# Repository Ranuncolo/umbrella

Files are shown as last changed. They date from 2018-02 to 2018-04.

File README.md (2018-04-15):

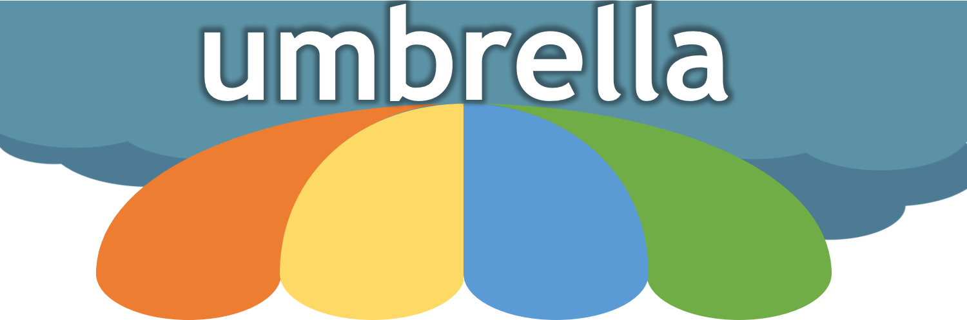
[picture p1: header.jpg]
Umbrella!


# umbrella

Umbrella is a weather station based on Raspberry Pi.

Umbrella!

Video demonstration:

https://www.youtube.com/watch?v=GxtKGGudiI4

## Introduction
Have you ever wondered what the local weather conditions are in your garden? Wouldn't you like a simple way to get all the necessary data for growing the best possible plants in your garden? 

We have created a Raspberry Pi based Weather station that collects and displays all its data in a very easy to understand graphed format. The device contains temperature, humidity, air pressure, ambient light and wind sensors.
It will also provide you weather data with up-to-the-minute precision.

This device will be significantly smaller and cheaper than a conventional weather station :)

## Technical Description

Although the weather can change relatively quickly, you don't need to sample the weather very frequently to plot interesting weather trends.  As this code will sample and record the weather every minute, a latency of a few seconds would be acceptable.  Only a single sample needs to be stored in the memory buffer at any one time as data can be saved to the SD card onboard the Pi.

Code is implemented in userspace.  The reduction in latency gained by running in kernel space is not required.  As the program is paired with a web app it is safer to deny the program access to the kernel, ensuring that the kernel remains protected.  This software required two threads - one for the data processing software and one for the web app.

Communication with the sensors is accomplished using the I<sup>2</sup>C protocol.  While the SPI protocol is much simpler and requires a lower processing overhead, the I<sup>2</sup>C protocol  only requires two lines connected to the Pi allowing for simpler circuitry.  Processing speed was not a priority for these devices.  For the wind speed however, an ADC with SPI was used to allow many samples to be taken across a short period of time.  The sensors contain internal reed switches that are triggered as the device rotates.  Counting rotations over a period of 3s allows a good average wind speed to be detected.

The project is split into roughly three equal parts.  Equal work share was ensured through constant communication with other group members and offering help where possible.   These parts were: 

1. Hardware and electronic circuit design - [Paul Harrison](http://github.com/pbh001)
2. Data processing onboard the Raspberry Pi - [Rene Gaio](http://github.com/Ranuncolo)
3. Data visualisation in a web browser - [Daniel Marwick](http://github.com/danmarwick)

Hardware was therefore allocated approximately one third of the time was spent on hardware and the rest on software.  Debugging of the hardware was done on a bread board as components arrived.  Debugging of software was done as features were coded. The connectivity of these parts of the system can be see in the block diagram below.

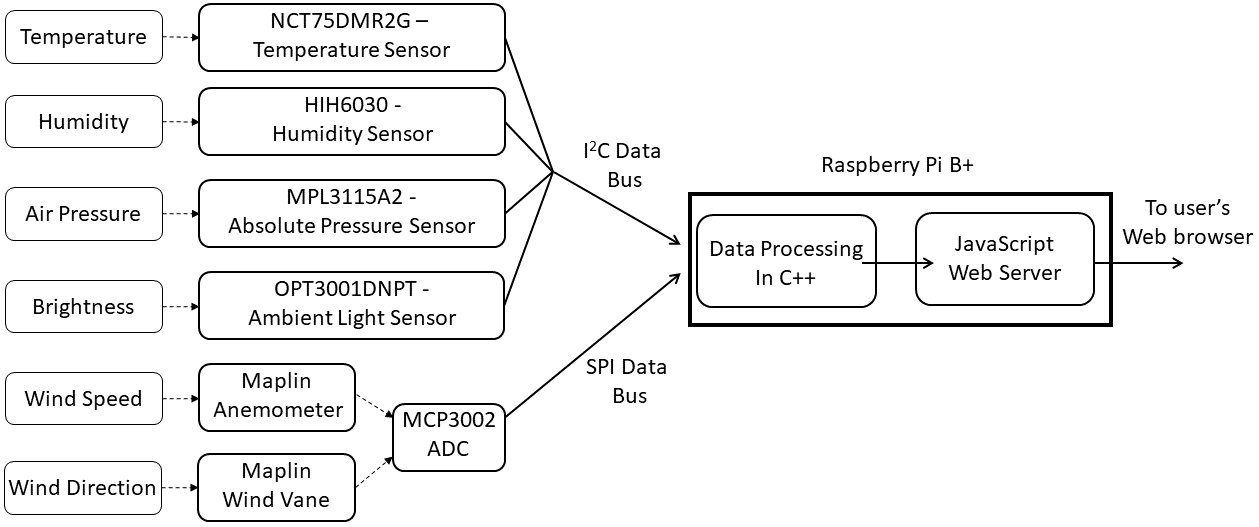
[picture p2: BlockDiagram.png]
Block Diagram


Data is read from the sensors in binary format, converted to numeric values and stored in human readable csv files with conventional SI units.  A web server script is running on the Pi listening for data requests in port 32000.  When a request is made by a web browser on the network, our web app is transmitted to said web browser.  The web app plots the data using the dygraphs package within Javascript.  The benefit of Javascript is the client side execution that allows the data to be plotted on the user's web browser without adding too much load to the processor on the Pi.

The device and software are marketed using Twitter and Facebook, sharing on relevant hashtags to reach our target market.  Version control is handled using git, with version 1.0 being our initial release when we reach a minimum viable product.  Hardware and software has been split between the team members as described above.

This project is deemed succesful when it is able to detect, record and display weather data in both real time and graphed formats.

## Required Components

1. Raspberry Pi Model B+ - (newer models are available and are recommended due to faster processor and onboard WiFi)

2. Sensors

   A. [NCT75DMR2G - I<sup>2</sup>C Digital Temperature sensor](http://uk.farnell.com/on-semiconductor/nct75dmr2g/temperature-sensor-3deg-c-msop/dp/2627996)

   B. [HIH6030 - I<sup>2</sup>C Digital Humidity sensor](http://uk.farnell.com/honeywell/hih6030-021-001/sensor-humidity-no-filter-4-5/dp/2356755?st=hih6030-021-001)

   C. [MPL3115A2 - I<sup>2</sup>C Digital Pressure sensor](http://uk.farnell.com/nxp/mpl3115a2/pressure-sensor-20-110kpa-8lga/dp/2009084)

   D. [OPT3001DNPT - I<sup>2</sup>C Digital Ambient Light Sensor](http://uk.farnell.com/texas-instruments/opt3001dnpt/ambient-light-sensor-uson-6/dp/2504234)
   
   E. [Maplin Anemometer](https://www.ebay.co.uk/p/Maplin-Replacement-Anemometer-for-Use-With-Wireless-Weather-Stations-N96gy/2254341215)
   
   F. [Maplin Wind Vane](https://www.ebay.co.uk/itm/Maplin-Replacement-Wind-Direction-Sensor-For-N96Fy-N96Gy-External-/201278499640)
   
3. [MCP3002 - SPI Analogue to Digital Converter](http://uk.farnell.com/microchip/mcp3002-i-p/ic-adc-10bit-200ksps-pdip-8/dp/1852015)

#### Notes
 - The I<sup>2</sup>C sensors require only four pins for the entire set of sensors.
 
        - Pin 1 - 3.3V
            
        - Pin 3 - Data
            
        - Pin 5 - Clock
           
        - Pin 6 - Ground
           
- Most devices used in this project are surface mount ICs that can be difficult to solder without access to the right equipment.  Hobbyists may wish to look for equivalent through-hole sensors that can be mounted to veroboard more easily for a simpler version that can be easily assembled at home.  

- The pressure sensor has an awkward package with a metal case and pads on the bottom surface. It is especially difficult to solder!

- Our wind sensors are mounted on a 3D printed arm with slightly imprecise measurements that required the wind sensors to be awkwardly bolted on.  When creating 3D printed elements be sure that your component will be compatible with the sensors.

- Due to time constraints we were unable to create a case or an outdoor power supply solution.  These are left as a project for you, dear reader!

## Installation Instructions

### Data Processing Software
When running your Raspberry Pi for the first time run the following in the terminal to locate and install any updates to the default packages.

 > sudo apt-get update
 
 > sudo apt-get upgrade

To enable I<sup>2</sup>C devices on your Raspberry Pi you must install the following package: 

 > sudo apt-get install i2c-tools
 
To enable our devices on your Raspberry Pi you must make the following change to the OS:

 > sudo raspi-config

Then go to Interfacing Options > Advanced > I2C > Enable
Also Interfacing Options > Advanced > SPI > Enable

In the final code it is possible to run all the sensors together compiling:

> g++ umbrella.cpp geti2c.cpp computation.cpp WindSpi.cpp -o weather

> ./weather

#### Notes
- When working with I<sup>2</sup>C sensors you must be careful to only read in the number of bits specified by the datasheet.  While you must read whole bytes from the chip, the relevant data is often comprised of a non-integer number of bytes - such as 12 bits.  Reading in these extra bits into your data can give erroneous readings.
- While all I<sup>2</sup>C sensors transmit data in a similar format, there are minor variations between each sensor and component manufacturers don't always write the clearest instructions.

### Javascript Web App
Adding webserver functionality to your Raspberry Pi is simple!  All you have to do is install Node.Js for Debian.  This can be accomplished using two commands:

> wget http://<i></i>node-arm.herokuapp.com/node_latest_armhf.deb

> sudo dpkg -i node_latest_armhf.deb

The first line should download the latest version of Node.Js for Debian.  The second command should install the package.

At this stage you should be able to run .js scripts from the command line using the command "node filename.js".  You can go one step further to get your web app code to launch when the Raspberry Pi boots up by editing your rc.local file.  As always, care should be taken when editing files that affect how the system boots up.  Small errors can easily prevent the device from starting at all!

First open the file with:

> sudo nano /etc/rc.local

then add the following line of code above the "exit 0" line.  Do not delete the "exit 0" line!

> sudo node ~/final/webserver.js &

If you save your code in a different folder then change the full path of the webserver.js file accordingly.

#### Notes
- The "&" symbol in the rc.local file is crucial for this code. It creates a new branch for the webserver code and allows it to run in the background.  If we were to omit this symbol then the Pi would wait for the script to finish executing before continuing with the boot process.  However, this code runs continuously so the boot process would never finish!
- The webserver code includes the IP address of the Pi and the port over which web app will be transmitted.  The IP address of your Pi on your network can be determined by typing "ifconfig" in the command line.  If you are unsure what ports are available for communication over your local network, then contact your network administrator.
  
### Contact    
    
Email: UmbrellaRPI@gmail.com
    
Twitter: https://twitter.com/UmbrellaRPI
    
Facebook: https://www.facebook.com/UmbrellaRPI

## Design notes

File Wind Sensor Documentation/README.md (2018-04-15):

# Wind Sensor Documentation

## Electronics and magnet of the Anemometer.
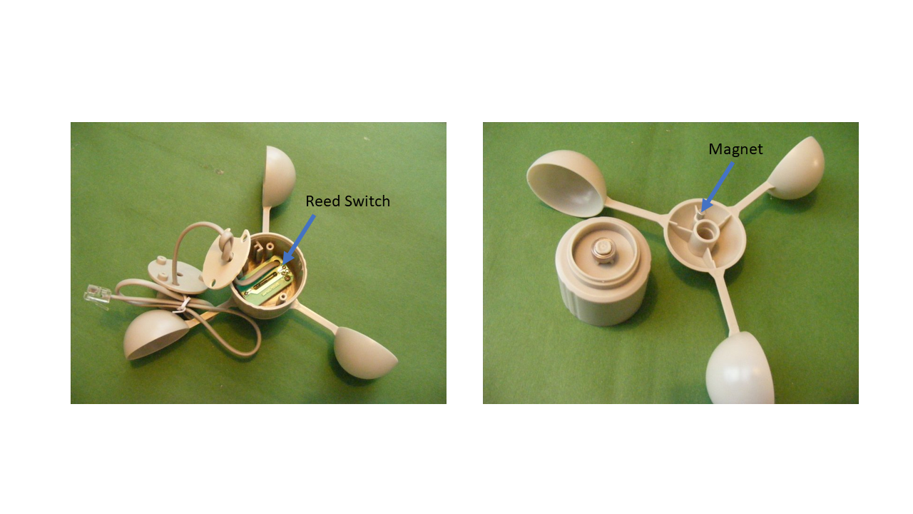
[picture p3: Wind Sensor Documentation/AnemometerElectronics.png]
Figure 1. Inner Electronics and magnet of the Anemometer.!


The figure above shows the electronics inside the anemometer which consists of a reed switch. A small magnet is attached to the rotator which closes the switch after every rotation by 180 degrees. Using C++ program WindSpiMain.cpp we can count the number times the switch is closed in a given time period.

## Electronics and magnet of the wind direction sensor (wind vane)
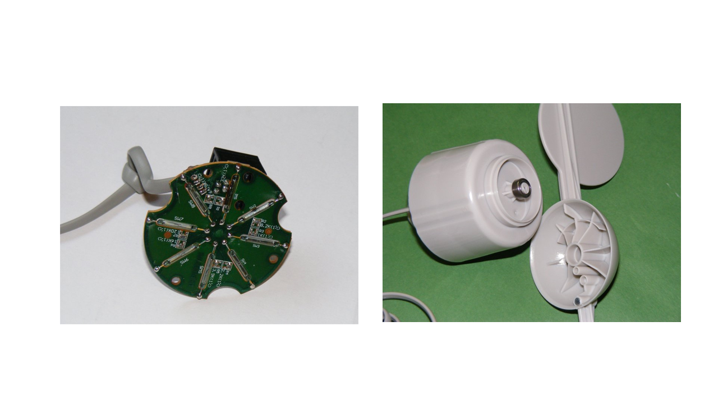
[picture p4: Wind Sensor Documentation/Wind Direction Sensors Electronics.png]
Figure 2. Inner Electronics and magnet of the wind direction sensor (wind vane).!
 

The figure above shows the electronics and magnet of the wind direction sensor (wind vane). It shows 8 reed switches arranged into a circle. Each switch is wired in series to a different resistor with values:	
33k*
6.57k
8.2k*
891R
1k*
678R
2.1k*
1.41k
3.9k*
3.13k
16k*
14.12k
120k*
42.12k
64.9k*
21,88k.	
The physical resistor values are given by the valus with an asterisk and the resistance formed by two switches being closed simultaneously are left without an asterisk. As the magent rotates it closes one or two switches at a time, which varies the voltage to the ADC and the digitized voltage output from the ADC is shown in the figure below. This way the direction of the vane is indicated. The figure below shows the voltage output from the ADC wind vane as it's rotated through 360 degress (and more). The voltages are plateaus indicating the direction.
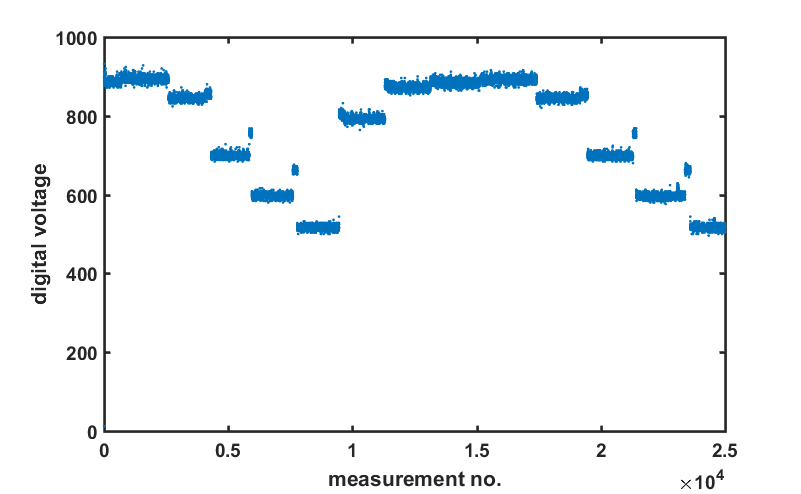
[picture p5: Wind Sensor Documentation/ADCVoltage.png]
Figure 3. Voltage output from the wind vane as the rotator is turned through more than 360 degrees.!


## Calculations to determine the number of kilo-samples per second needed

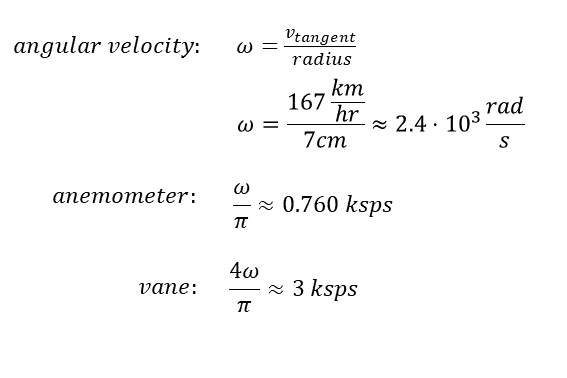
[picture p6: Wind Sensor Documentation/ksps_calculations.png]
Figure 4. Calculations to determine the number of kilo-samples per secend needed.!


The figure above shows the number of kilo-samples per second (ksps) required to measure a wind-speed of 100mph (167 km/hr). First the angular veocity is calculated from the tangential velocity (167km/hr) divided by the length of the rotator arm (7cm). Then the angular velocity is divided by pi which is the angle traversed between closed swtiches (voltage highs). For the wind vane the angular velocity is divided by pi/4 since there are 4 voltage plateaus in a 180 degree rotation as shown in voltage output from the ADC. To satisfy the Nyquist theorem and measure higher wind speeds a sampling rate of approximately 25 ksps was chosen. Our ADC was a MCP3002 which can handle up to 200ksps. 
## Wind sensor holder (3D printed)
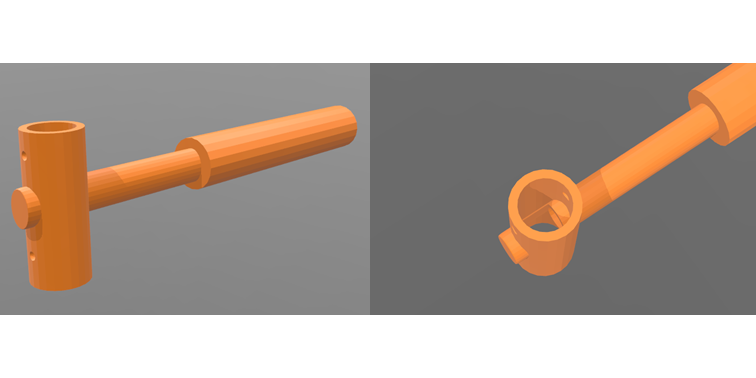
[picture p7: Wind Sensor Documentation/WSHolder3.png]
Figure 5. CAD designs of wind sensor holder.


To hold the wind sensors together in a convenient way a holder was 3D printed. The figure above shows the CAD drawings that were made. Screw holes were added to attach the sensors to and the object is hollow so that the wires can be feed through to the RPi. The figure below shows the finished result.

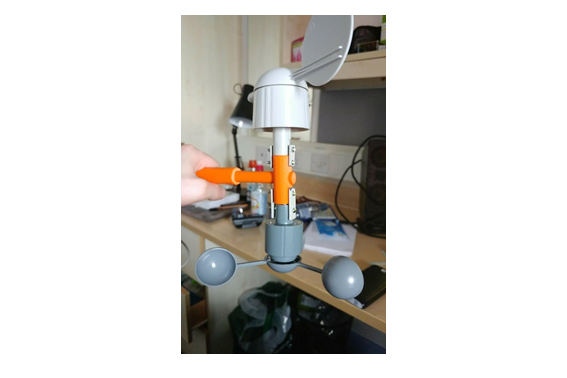
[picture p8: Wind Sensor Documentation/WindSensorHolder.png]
Figure 6. Three-D printed wind sensor holder.


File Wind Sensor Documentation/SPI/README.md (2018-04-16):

//By Paul Harrison
===========================================================================================================

Description: The WindSpi class enables the Raspberry Pi to communicate with the MCP002 SPI ADC using spidev. The class can be easily modified to enable the Raspberry Pi to communicate with other SPI devices.

============================================================================================================

To build on the Raspberry Pi:

g++ -c WindSpiMain.cpp
g++ -fpermissive -Wall WindSpi.cpp WindSpiMain.cpp -o outBin

Make sure that the WindSpi.h header file is in the work directory.
Run ./outBin. The output is a file with current time as the filename and contains the wind speed and direction.

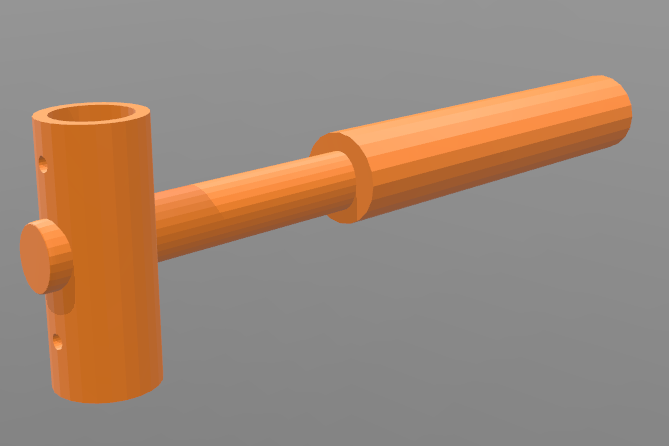
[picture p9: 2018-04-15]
Wind Sensor Documentation/WSHolder1.png

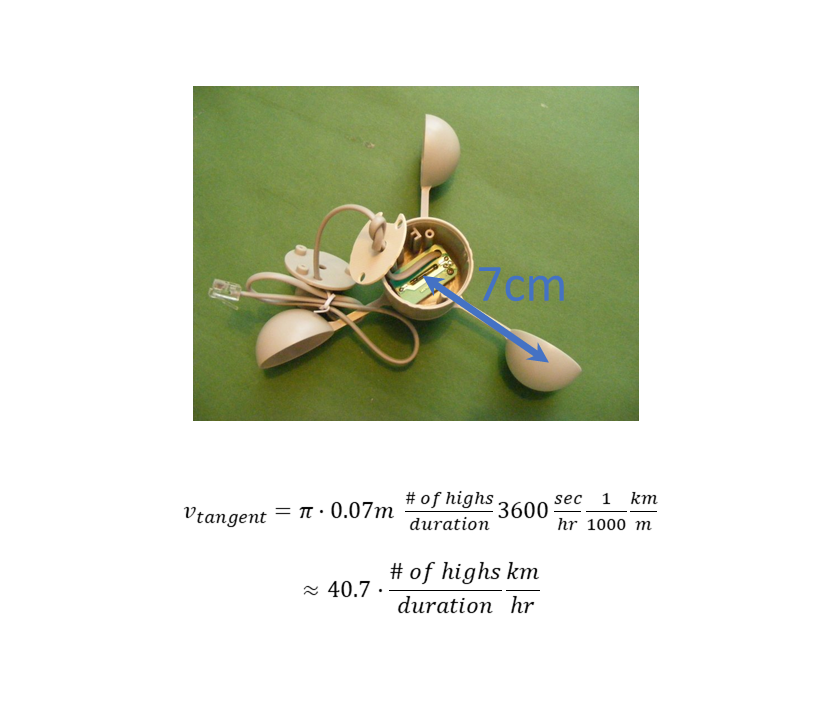
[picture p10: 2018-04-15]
Wind Sensor Documentation/WindSpeedSensor.png

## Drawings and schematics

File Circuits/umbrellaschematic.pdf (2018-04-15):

15/04/2018 18:10 f=1.03 E:\Realtime Embedded Programming\PCB\PIPCB.sch (Sheet: 1/1) SpiceOrder 1 SpiceOrder 2 | SpiceOrder 1 SpiceOrder 2
SpiceOrder 2 | SpiceOrder 1 | SpiceOrder 1 SpiceOrder 2 | SpiceOrder 1 SpiceOrder 2 SpiceOrder 1 SpiceOrder 2 | SpiceOrder 1 SpiceOrder 2 | SpiceOrder 1 SpiceOrder 2

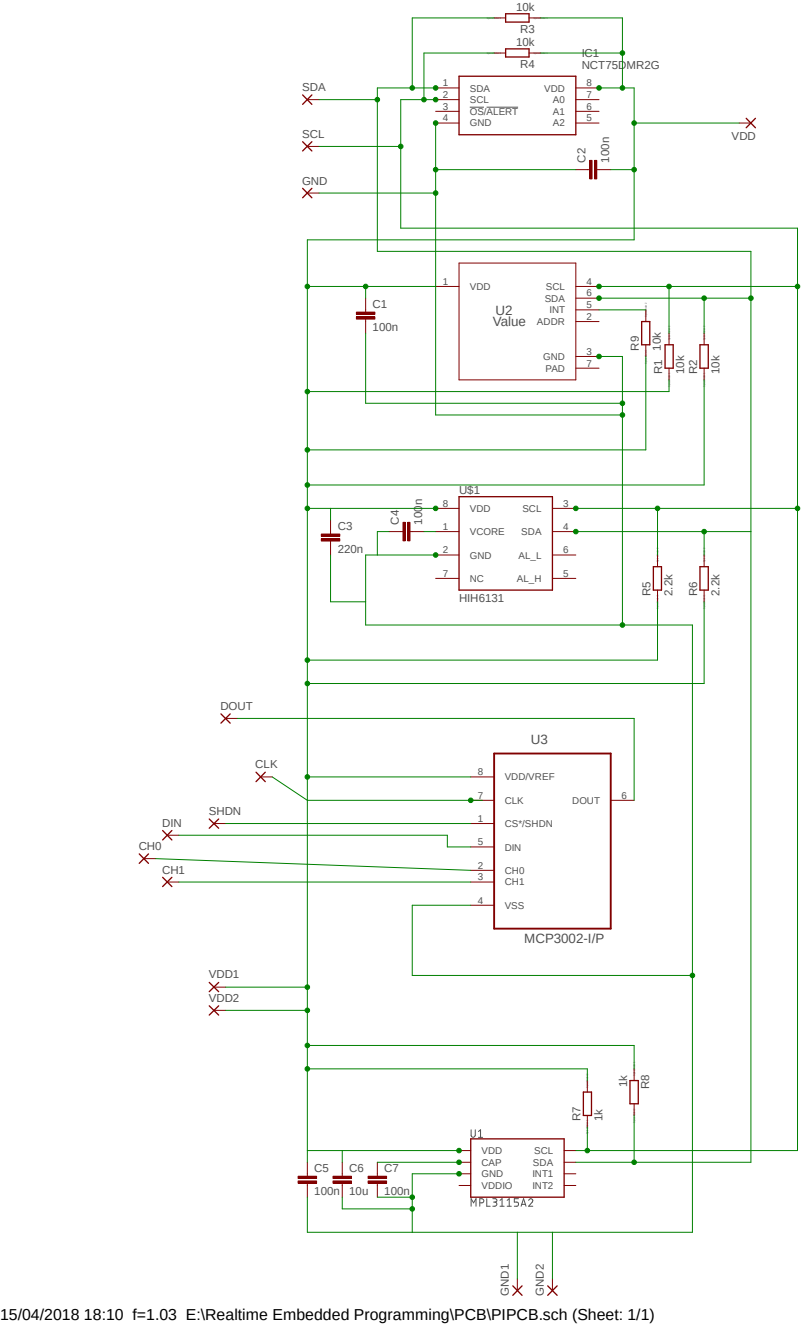
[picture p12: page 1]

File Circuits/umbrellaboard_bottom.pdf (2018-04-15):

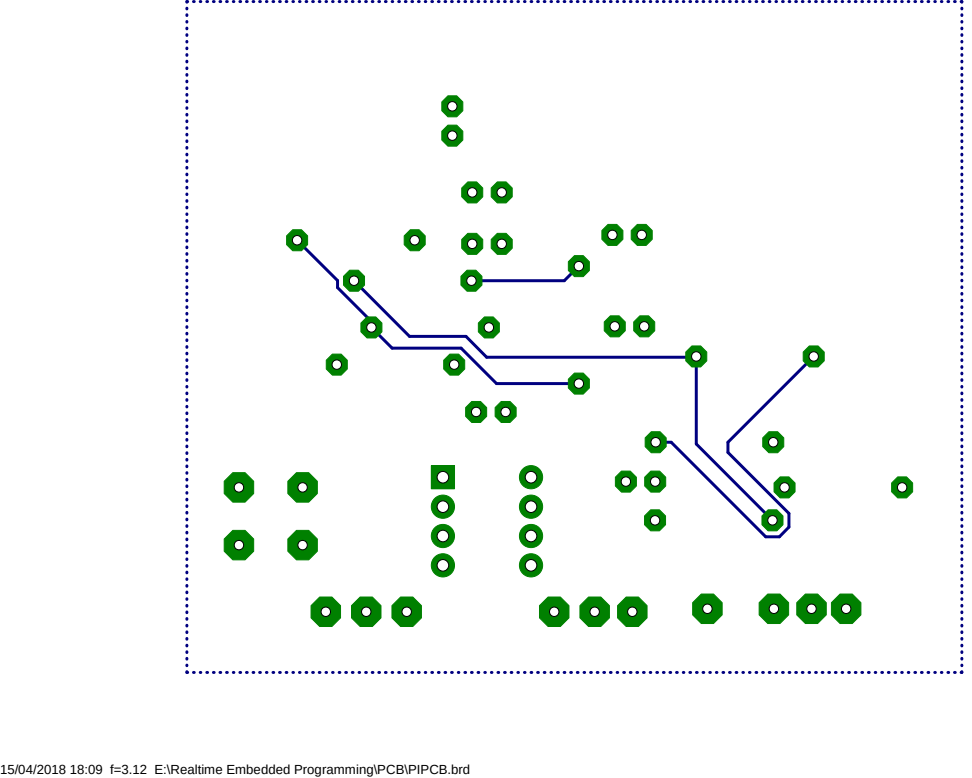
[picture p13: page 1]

15/04/2018 18:09 f=3.12 E:\Realtime Embedded Programming\PCB\PIPCB.brd

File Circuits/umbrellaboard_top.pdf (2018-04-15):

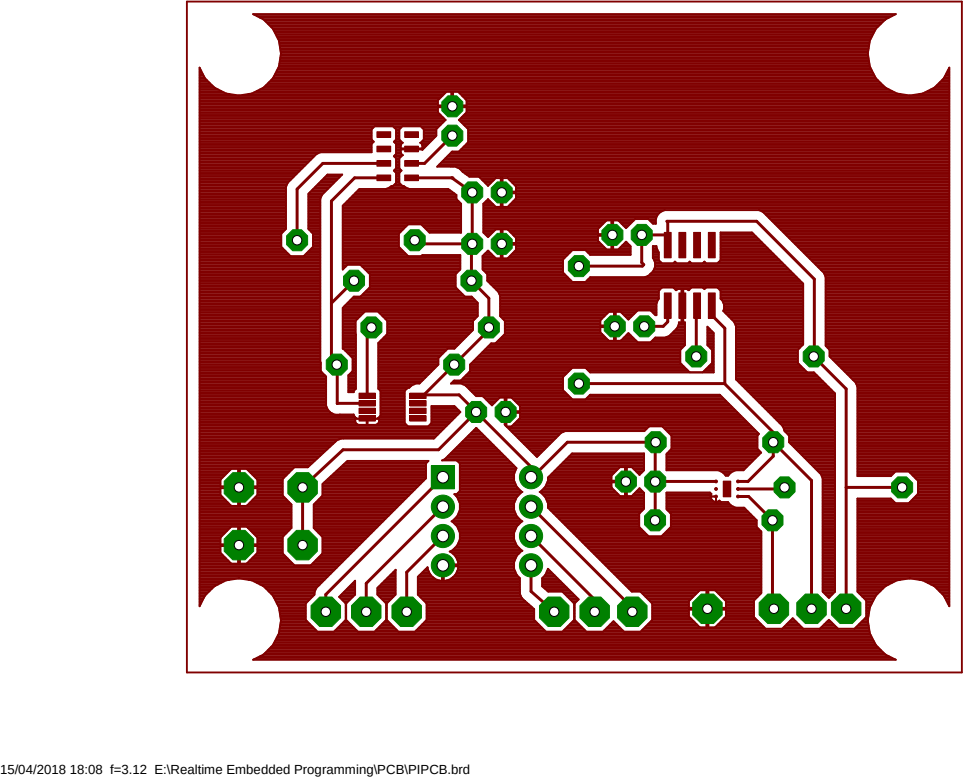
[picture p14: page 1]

15/04/2018 18:08 f=3.12 E:\Realtime Embedded Programming\PCB\PIPCB.brd

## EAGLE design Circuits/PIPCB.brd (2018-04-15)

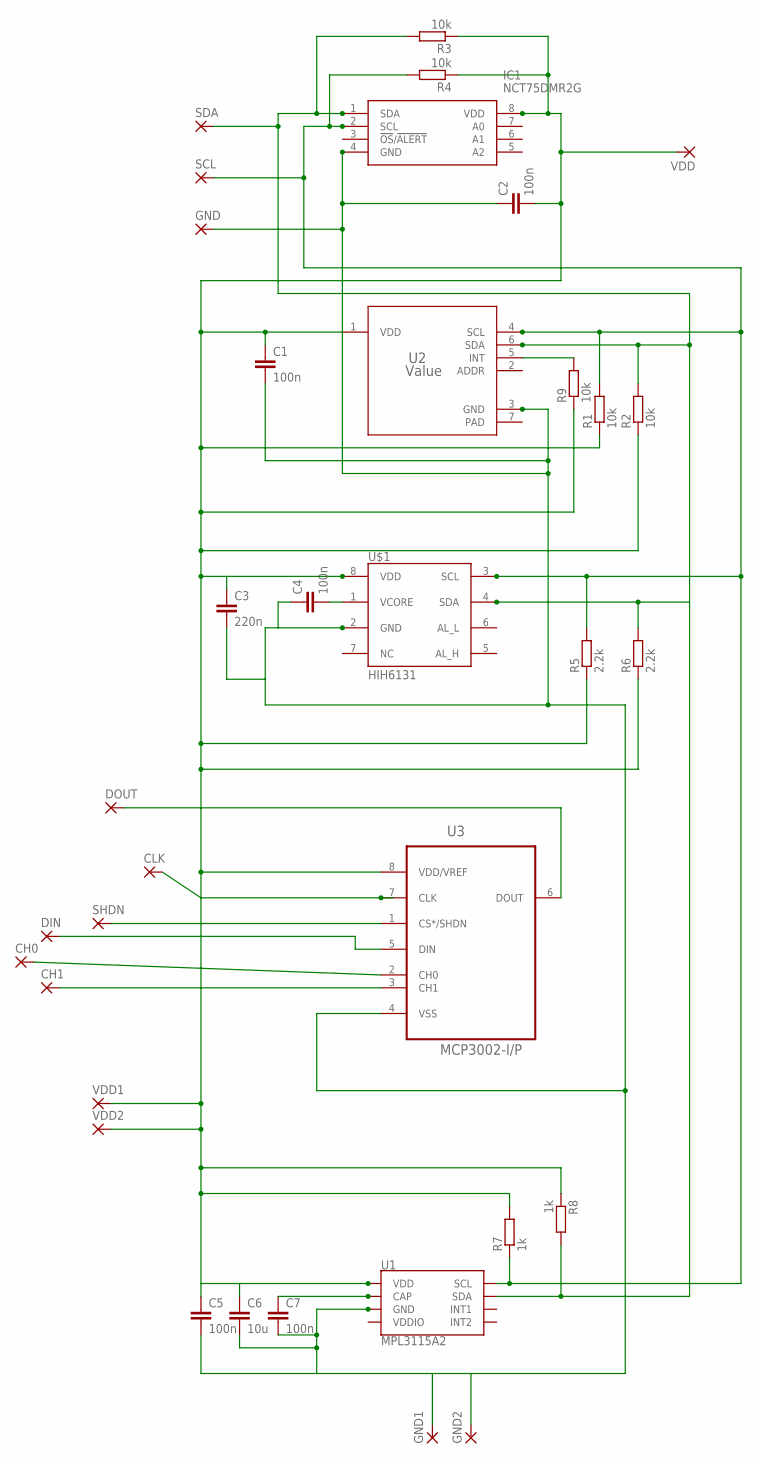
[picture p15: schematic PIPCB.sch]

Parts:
C1, C2, C4, C5, C7: 100n; C2.5-3
C3: 220n; C2.5-3
C6: 10u; C2.5-3
CH0, CH1: 2,54/0,8
CLK: 2,54/0,8
DIN: 2,54/0,8
DOUT: 2,54/0,8
GND, GND1, GND2: 2,54/0,8
IC1: NCT75DMR2G; SOP65P490X110-8N
R1, R2, R3, R4, R9: 10k; 0207/10
R5, R6: 2.2k; 0207/10
R7, R8: 1k; 0207/10
SCL: 2,54/0,8
SDA: 2,54/0,8
SHDN: 2,54/0,8
U1: MPL3115A2; LGA-8-5X3
U2: Value; DNP0006A
U3: MCP3002-I/P; DIP254P762X533-8
U$1: HIH6131; SOIC8
VDD, VDD1, VDD2: 2,54/0,8

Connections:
GND: C1.2, C2.1, C3.2, C4.1, C5.2, C6.2, C7.2, GND.1, GND1.1, GND2.1, IC1.4 (GND), U1.3 (GND), U2.3 (GND), U3.4 (VSS), U$1.2 (GND)
unnamed: C1.1, C2.2, C3.1, C5.1, C6.1, IC1.8 (VDD), R1.1, R2.1, R3.1, R4.1, R5.1, R6.1, R7.2, R8.1, R9.1, U1.1 (VDD), U2.1 (VDD), U3.8 (VDD/VREF), U$1.8 (VDD), VDD.1, VDD1.1, VDD2.1
unnamed: IC1.2 (SCL), R1.2, R4.2, R5.2, R7.1, SCL.1, U1.8 (SCL), U2.4 (SCL), U$1.3 (SCL)
unnamed: IC1.1 (SDA), R2.2, R3.2, R6.2, R8.2, SDA.1, U1.7 (SDA), U2.6 (SDA), U$1.4 (SDA)
unnamed: C4.2, U$1.1 (VCORE)
unnamed: DOUT.1, U3.6 (DOUT)
unnamed: CLK.1, U3.7 (CLK)
unnamed: SHDN.1, U3.1 (CS*/SHDN)
unnamed: C7.1, U1.2 (CAP)
unnamed: DIN.1, U3.5 (DIN)
unnamed: CH0.1, U3.2 (CH0)
unnamed: CH1.1, U3.3 (CH1)
unnamed: R9.2, U2.5 (INT)
VDDIO: U1.4 (VDDIO)

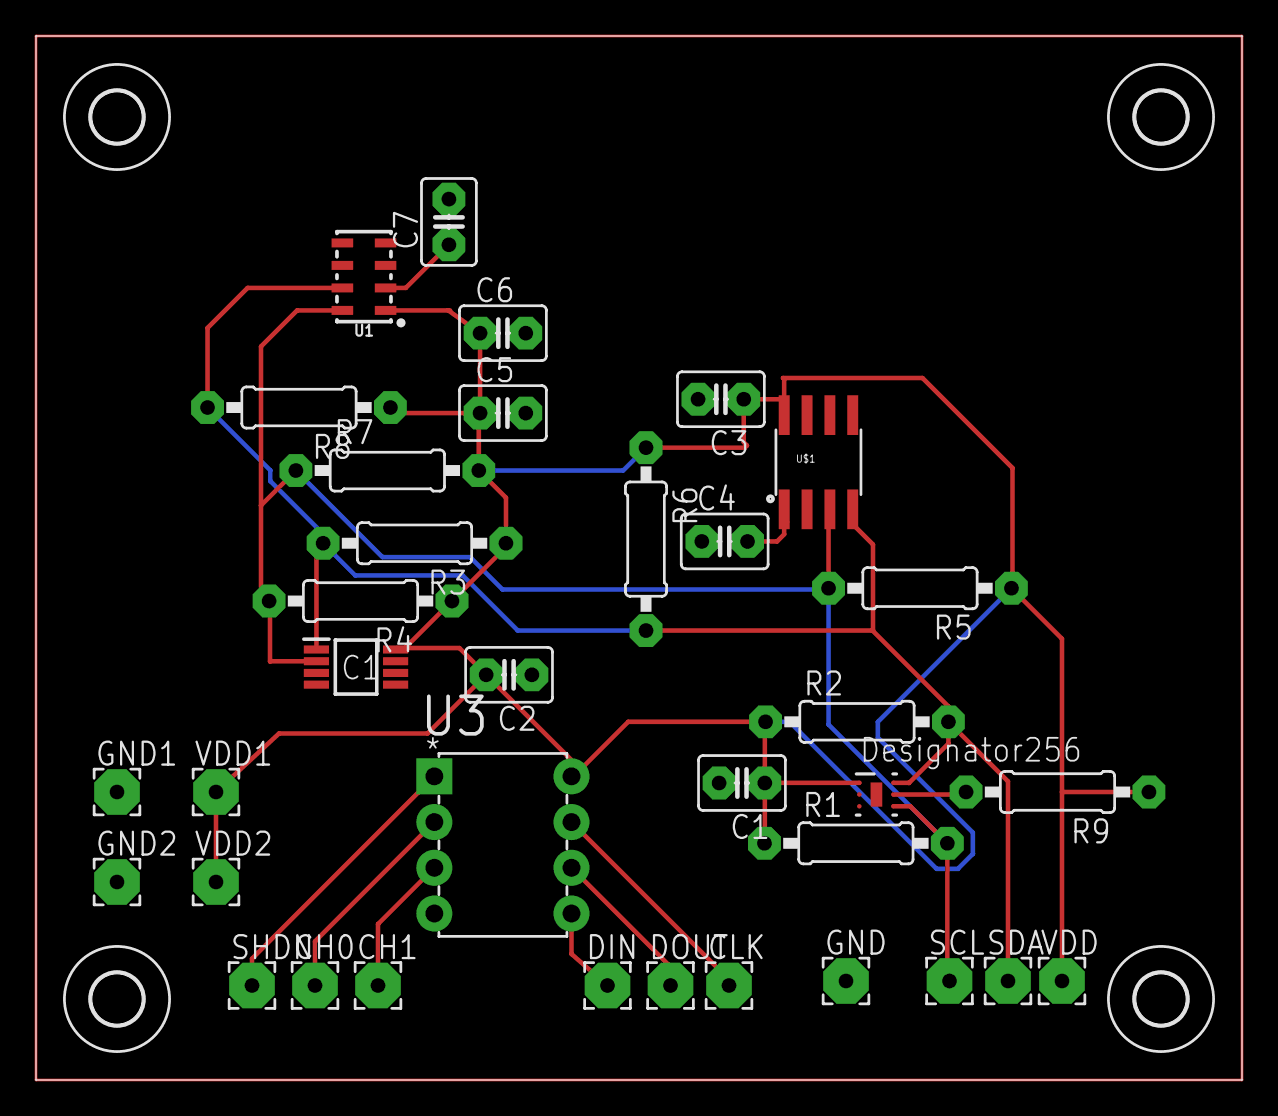
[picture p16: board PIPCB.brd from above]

Board: 2 copper layers, 67.0 x 58.0 mm, 39 parts (0 on the bottom side), 13 nets.

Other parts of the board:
U$4, U$5, U$6, U$7: 2,8

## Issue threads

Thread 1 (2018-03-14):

Hardware + software block diagrams

npes-95, 2018-03-14:
Useful for quickly understanding how your system works.

- Team 4

danmarwick, 2018-03-16:
Hi! I've added a block diagram on our front page showing a flow of information through this system. Is this what you had in mind?

danmarwick, 2018-03-20:
I'll assume the block diagram is clear enough and close this issue.  If you have any other comments then let us know and we'll be happy to make updates!

Daniel - Team 13

Closed 2018-03-20.

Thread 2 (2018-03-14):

Issues

alex-angelov, 2018-03-14:
1) There is no list of exact component models/manufacturers, or a sketch/CAD of the system design;
2) Power considerations - will the Pi (assuming you won't use a PSU) be able to supply enough power for the motor;
3) If it is operating outside, what kind of weather protection (electronics) are you going to implement? How are you powering the system?
4) A small schematic outlining a typical example with a garden and sensor locations would be great for visualization;
5) Maybe write the name of the sensors, because components can disappear from stores with time.
Good idea overall.
-Team 11

danmarwick, 2018-03-22:
Hi Alex,
We've now included the design of our PCB and added our hardware details.  Is there anything else you would like cleared up?

Daniel - Team 13

alex-angelov, 2018-03-23:
I think this is all, great work!

Closed 2018-03-23.

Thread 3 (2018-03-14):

Maybe add a photo of the whole system flow is better to understand

JiananKan, 2018-03-14:
team6

danmarwick, 2018-03-16:
Hi!  I've added a block diagram on our front page showing a flow of information through this system.  Is this what you had in mind?

danmarwick, 2018-03-20:
Hi Jianan,

I'll assume the block diagram is clear enough and close this issue. If you have any other comments then let us know and we'll be happy to make updates!

Daniel - Team 13

Closed 2018-03-20.

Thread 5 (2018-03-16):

Could we see what you're doing to get this project to completion?

acra6488, 2018-03-16:
Do you have any pictures of testing, or a link to a social media page?
Which parts have caused problems and how did you solve them? Perhaps this could appear in your Wiki under a "Troubleshooting" section.
-Aurelie -Team 2

danmarwick, 2018-03-18:
Hi Aurelie,

1. We've been testing the project continuously in the lab over the last few weeks but unfortunately we haven't documented our initial testing with pictures or video.  We didn't think our initial poorly wired bread board could be used for any effective marketing!

2. Social media links are included at the bottom of our main page.  Our social media campaign should start up soon as the final design comes together.

3. Great idea with the troubleshooting section!  I've combined this with Tamer's idea for the installation guide so prospective users can get up and running while avoiding all the pit falls we did!

Daniel - Team 13

danmarwick, 2018-03-24:
Hi Aurelie,
Following up with this - we've now added some notes on problem solving and troubleshooting to our installation guide for all parts of the project.  We've also started our social media campaign!

Twitter: https://twitter.com/UmbrellaRPI
Facebook: https://www.facebook.com/UmbrellaRPI/

Is there anything else you would like us to add or expand on?

Daniel - Team 13

Closed 2018-03-25.

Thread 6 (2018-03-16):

Repo Structuring

CalumWest, 2018-03-16:
More explicit structuring of repository including hardware specs/resources and code structuring would be useful

danmarwick, 2018-03-22:
Hi Calum,

1. We've cleared up our repository so the code structure should be clearer.  Web app code, SPI code for wind sensors and I2C code for everything else is currently separated.  We're currently working on bringing it all together.

2. Hardware specifications are on the front page and our PCB design have now been included.

Is that all good? Is there anything else you would like cleared up?

Daniel - Team 13

Closed 2018-03-24.

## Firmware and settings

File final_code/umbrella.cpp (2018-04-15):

//
//  umbrella.cpp
//
//

/* C++ code for umbrella - weather station on RPi.
 
 umbrella - weather station sensor are:
 - temperature sensor;
 - humidity sensor;
 - pressure sensor;
 - light sensor.
 
 They all follow I2C bus protocol where, according to https://pinout.xyz/pinout/i2c:
 PIN 1 - 3V3 Power;
 PIN 3 - BCM2 Data;
 PIN 5 - BCM3 Clock;
 PIN 6 - Ground.
 
 Data are sampled once every 15 minutes (value that can be easily changed), stored in a .txt file and finally shown online through web browser. The name of the file is the daily data: YY-MM-DD.
 
 +++ NEED TO CHOOSE HOW TO CHANGE THE DAY, IF AT 00.00?
 
 To compile, easily type: g++ umbrella.cpp -o <your_name>
 where "<your_name>" can be anything you wish.
 
 ex:
 $ g++ umbrella.cpp geti2c.cpp computation.cpp -o weather
 $ ./weather
 
 */
// ************************************************************************
// Libraries:

// general
#include <iostream> // for cout <<
#include <fstream> // for open/write/close file
#include <ctime> // output file name and timing in the file.
#include <cmath> // for NAN, pow

// for i2c +++ check if .h is required
#include <linux/types.h>
#include <linux/i2c-dev.h>
#include <sys/ioctl.h>
#include <unistd.h> // for read()
#include <fcntl.h> // Required for O_RDWR
#include <bitset> // required for bit operation

#include <cstdio>
#include "computation.hpp"
using namespace std;


// ************************************************************************
// Definition of constants:

static const char *device = "/dev/i2c-1"; //for our RPi, other may have 0

// Definition of each different address.
/* Every sensors have its own address. It is possible to retrieve it typing: $ sudo i2cdetect -y 1
 
 -y:  is just for avoiding a "are you sure you want to continue?"
 1 : is because we have a rev2 RPi, 0 for rev1 RPi.
 
 Each address is written in hex - notation.
 */

static int temp_add = 0x48;
static int hum_add = 0x27;
static int pres_add = 0xC0;
static int lux_add = 0x44;

//+++ Check, not all are correct.

int main()
{
    // Definition of values:
    double Temperature = NAN;
    double Humidity = NAN;
    double Pressure = NAN;
    double Light = NAN;
    double Wind = NAN;
    int Nord = 0;
    // ********************************************************************
    // Creation of the output file:
    // File name is the current local time. It requires <ctime>.
    // More info at http://www.cplusplus.com/reference/ctime/strftime
    
    time_t moment;      //name of the chosen object, moment.
    struct tm *tpointer;
    char filename[20]; //it's not so long actually, but you never know
    time(&moment); // I'm giving in input the address of my obj moment
    tpointer = localtime(&moment); // And I store this in tpointer
    
    // Now I can "build up" the filename:
    strftime(filename,20,"%H_%M_%S.txt",tpointer);
    cout << "Data of this run are stored in " << filename << endl;
    
    // Now I create and open the output file.
    ofstream file;
    file.open(filename);
    
    // check:
    if (!file)
    {
        cout << "unable to open it." << endl;
        return 1;
    }
    
    // First output
    file << "umbrella - weather station." << endl;
    file << "Welcome!" << endl;
    file << endl;
    file << "------------------------------------------" << endl;
    file << endl;
    
    //  ********************************************************************
    // Header of the output file:
    
    cout << "Epoch\t\t Temp [C]\t Hum [%]\t Pres [Pa]\t Light [lux]" << endl;
    file << "Epoch\t\t Temp [C]\t Hum [%]\t Pres [Pa]\t Light [lux]" << endl;
    
    // Start the while loop:
    while(1) //+++ I LL HAVE TO CHOOSE A PROPER WHILE, WHILE THE DAY
    {
        char Epoch[18] = {};
        epoch(*Epoch);
        
        Temperature = calc_temp();
        Humidity = calc_hum();
        Pressure = calc_press();
        Light = calc_lux();
        Wind = wind();
        Nord = compass();
        
        char NSWE = '-';
        if (Nord == 1)
        {
            NSWE = 'N';
        }
        if (Nord == 2)
        {
            NSWE = 'W';
        }
        if (Nord == 3)
        {
            NSWE = 'S';
        }
        if (Nord == 4)
        {
            NSWE = 'E';
        }
        else
        {
            NSWE = '-';
        }
        
        // Writing in the output file:
        
        cout << Epoch   << "\t" <<  Temperature
                        << "\t\t" <<  Humidity
                        << "\t\t" <<  Pressure
                        << "\t\t" <<  Light
                        << "\t\t" << Wind << " " << NSWE 
                        << endl;
        
        file << Epoch   << "\t" <<  Temperature
                        << "\t\t" <<  Humidity
                        << "\t\t" <<  Pressure
                        << "\t\t" <<  Light
                        << endl;
        
        
        // ****************************************************************
        // Wait 15 minutes
        int min = 15; // minutes you want to wait --> sample time
        int msec = min * 60 * 1000 * 1000;
        msec = 1000000; //+++
        usleep(msec); //usleep is in microsecond, so 900 x 10^6 microsec
        
        
        
    }
    
    file.close();
    return 0;
}

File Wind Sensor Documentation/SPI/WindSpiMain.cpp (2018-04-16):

//By Paul Harrison
/***********************************************************************
 *
  Program to calculate the rotational velocity of an anemometer with arm length 7cm.
  Anemometer consists of a magnetic reed switch and rotating propellers which carry a magnet
  that trips the reed switch twice per 360 degree rotation.

 Secondly this program finds the wind direction from the output voltage of the wind vane. The output voltages form plateaus (or here thery are called bands) that indicate direction (i.e. each voltage is associated which a different direction, North, East, etc). WindSpiMain.cpp.Pprogram that tests the WindSpi class.
 * a WindSpi class object (a2d) is created. the a2d object is instantiated
 * using the overloaded constructor. which opens the spidev0.0 device with
 * SPI_MODE_0 (MODE 0) (defined in linux/spi/spidev.h), speed = 1MHz &
 * bitsPerWord=8.
 *
 * call the spiWriteRead function on the a2d object 20 times. Each time make sure
 * that conversion is configured for single ended conversion on CH0
 * i.e. transmit ->  byte1 = 0b00000001 (start bit)
 *                   byte2 = 0b1000000  (SGL/DIF = 1, D2=D1=D0=0)
 *                   byte3 = 0b00000000  (Don't care)
 *      receive  ->  byte1 = junk
 *                   byte2 = junk + b8 + b9
 *                   byte3 = b7 - b0
 *    
 * after conversion must merge data[1] and data[2] to get final result
 *
 *
 *
 * *********************************************************************/
#include "WindSpi.h"
#include <cstdio>
#include <ctime>
#include <iostream>
#include <fstream>
 
using namespace std;
 
int main(void)
{
    WindSpi a2d("/dev/spidev0.0", SPI_MODE_0, 1000000, 8);
    	int i = 25000;
	int ii = 25000;
        int a2dVal = 0;
        int a2dChannel = 7;
        unsigned char data[3];
 	int a2dVal_new = 0;
	int a2dVal_old = 0;
	double highs = 0.0;
	double vel;

	 std::clock_t start;
    double duration;


	time_t moment;      //name of the chosen object, moment.
    struct tm *tpointer;
    char filename[20]; //it's not so long actually, but you never know
    time(&moment); // I'm giving in input the address of my obj moment
    tpointer = localtime(&moment); // And I store this in tpointer
    
    // Now I can "build up" the filename:
	strftime(filename,20,"%H_%M_%S.txt",tpointer);
	ofstream file;
	file.open(filename);
    
    // check:
    if (!file)
    {
        cout << "unable to open it." << endl;
        return 0;
    }
    
    // First output
    file << "Long time no see :)" << endl;
	file << endl;

    start = std::clock();	//start clock

    while(i > 0)
    {
	// SPI
        data[0] = 1;  //  first byte transmitted -> start bit
        data[1] = 0b10000000 |( ((a2dChannel & 7) << 4)); // second byte transmitted -> (SGL/DIF = 1, ODD/SIGN = 1 )
        data[2] = 0; // third byte transmitted....don't care
 
        a2d.spiWriteRead(data, sizeof(data) );
 
        a2dVal = 0;
                a2dVal = (data[1]<< 8) & 0b1100000000; //merge data[1] & data[2] to get result
                a2dVal |=  (data[2] & 0xff);


	a2dVal_new = a2dVal;	//update value
	if( (a2dVal_new > 800) && (a2dVal_old < 800)){	//check for initial high value
	highs = highs + 1.0;}		//count high values
	
        i--;
	
	a2dVal_old = a2dVal_new; 	// update old value for next iteration
    }
	 duration = ( std::clock() - start ) / (double) CLOCKS_PER_SEC;		//check time duration
	if(highs == 1){
	vel = 0;
	} else {
	vel = 3.60*2.00*3.14*0.07*highs/(2.00*duration); // calculate velocity: vel = 3.6km/hr * 2pi * 7 cm * (number of high values/2)/(measurement time)
	}
	 cout << "Wind Speed is: " << vel  << " km/hr" <<  endl;
	 cout << "duration: " << duration <<  endl;
         cout << "highs: " << highs <<  endl;

	time_t epoch;      //name of the chosen object, moment.
        struct tm *tepoch;
        char times[10]; //it's not so long actually, but you never know
        time(&epoch); // I'm giving in input the address of my obj moment
        tepoch = localtime(&epoch); // And I store this in tpointe
        strftime(times,10,"%H:%M:%S",tepoch);
	

	file << "Epoch" << endl;
	file << times << "\t" << endl;
	file << "Wind Speed is: " << vel << "\n";
		
	// Voltafge bands indicate direction
	int band1 = 0;
	int band2 = 0;
	int band3 = 0;
	int band4 = 0;

    a2dChannel = 0;
    while(ii > 0)
    {
	data[0] = 1;  //  first byte transmitted -> start bit
        data[1] = 0b10000000 |( ((a2dChannel & 7) << 4)); // second byte transmitted -> (SGL/DIF = 1, ODD/SIGN = 0)
        data[2] = 0; // third byte transmitted....don't care

        a2d.spiWriteRead(data, sizeof(data) );

        a2dVal = 0;
                a2dVal = (data[1]<< 8) & 0b1100000000; //merge data[1] & data[2] to get result
                a2dVal |=  (data[2] & 0xff);
	
	
	if((a2dVal < 980) && (a2dVal > 908)){
	band1 = band1 + 1;}
        if((a2dVal < 190) && (a2dVal > 150)){
        band2 = band2 + 1;}
        if((a2dVal < 780) && (a2dVal > 750)){
        band3 = band3 + 1;}
        if((a2dVal < 510) && (a2dVal > 475)){
        band4 = band4 + 1;}
        if((a2dVal < 700) && (a2dVal > 645)){
        band3 = band3 + 1;}
        if((a2dVal < 1020) && (a2dVal > 960)){
        band4 = band4 + 1;}
		
        ii--;
    }

    int V [4] = {band1, band2, band3, band4};
    int  max = band1;
    int iii = 3;
  
    while( iii > 0 )
    { 
      if(max < V[iii]){
      max = V[iii];}
      iii--;
    }

//Band with the most counts is the current direction
if(max == band1){
file << "Direction is: N \n";
}
if(max == band2){
file << "Direction is: W \n";
}
if(max == band3){
file << "Direction is: S \n";
}
if(max == band4){
file << "Direction is: E \n";
}
	cout << band1 << endl;
        cout << band2 << endl;
	cout << band3 << endl;
	cout << band4 << endl;
	cout << "Max: " << max << endl;

file.close();	

	
    return 0;
}

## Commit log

2018-02-06 temperature reading
2018-02-27 one wire protocol
2018-03-18 Add files via upload
    SPI code for wind sensors
2018-03-18 Add files via upload
    Link to video showing testing of our wind sensors using SPI interfacing.
2018-03-20 main I2C code
2018-03-21 Add files via upload
    Schematic and PCB design for our sensors and ADC.
2018-03-21 Add files via upload
    Schematic and PCB of our sensors and ADC.
2018-03-28 almost final version
    need to complete pressure and format output
2018-04-01 Updated PCB
    [PIPCB.BRD, PIPCB.SCH]
2018-04-15 Final Circuit Files
    [PIPCB.brd, PIPCB.sch]

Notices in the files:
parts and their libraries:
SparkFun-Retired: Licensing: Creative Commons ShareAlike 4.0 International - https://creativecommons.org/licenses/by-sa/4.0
